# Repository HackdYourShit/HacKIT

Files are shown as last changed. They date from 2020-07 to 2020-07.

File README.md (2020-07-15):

# HacKIT
a low to high tech civic privacy hard(wear) kit for the reclaiming, redesigning, and hacking of the Amazon Echo, Google Home, Apple Siri.

Go [here](https://www.instructables.com/id/HacKIT-a-Civic-Privacy-Hardwear-Kit-for-Hacking-Al/) for a step-by-step build guide for HacKIT.

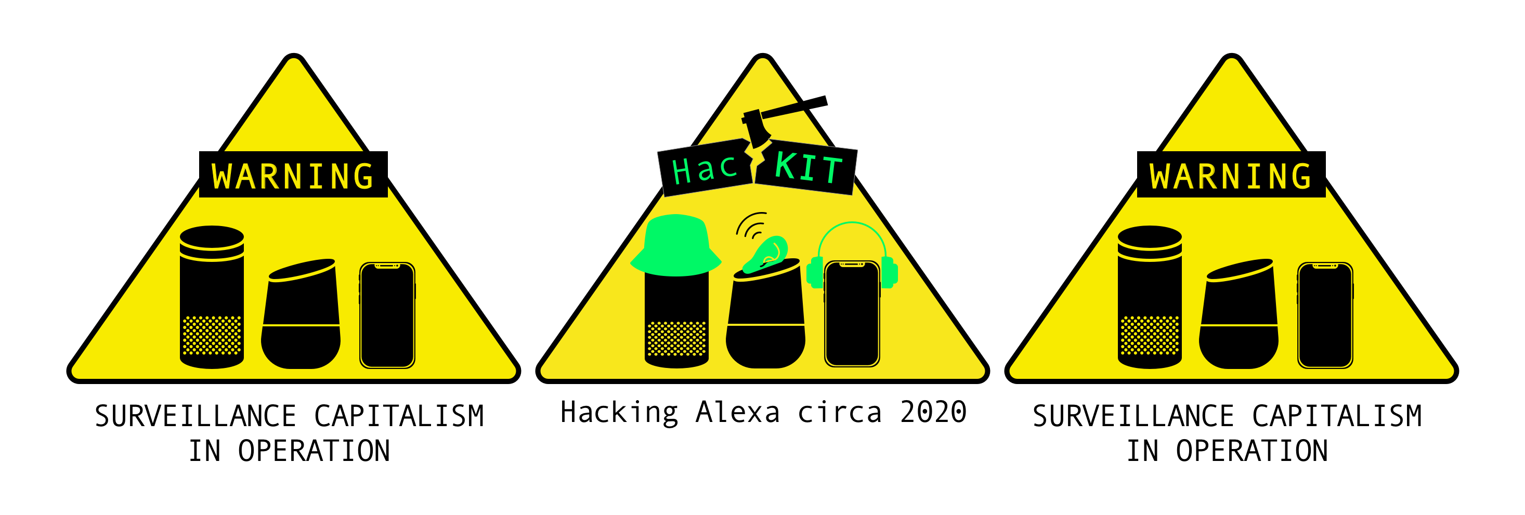
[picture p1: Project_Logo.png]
GitHub Logo


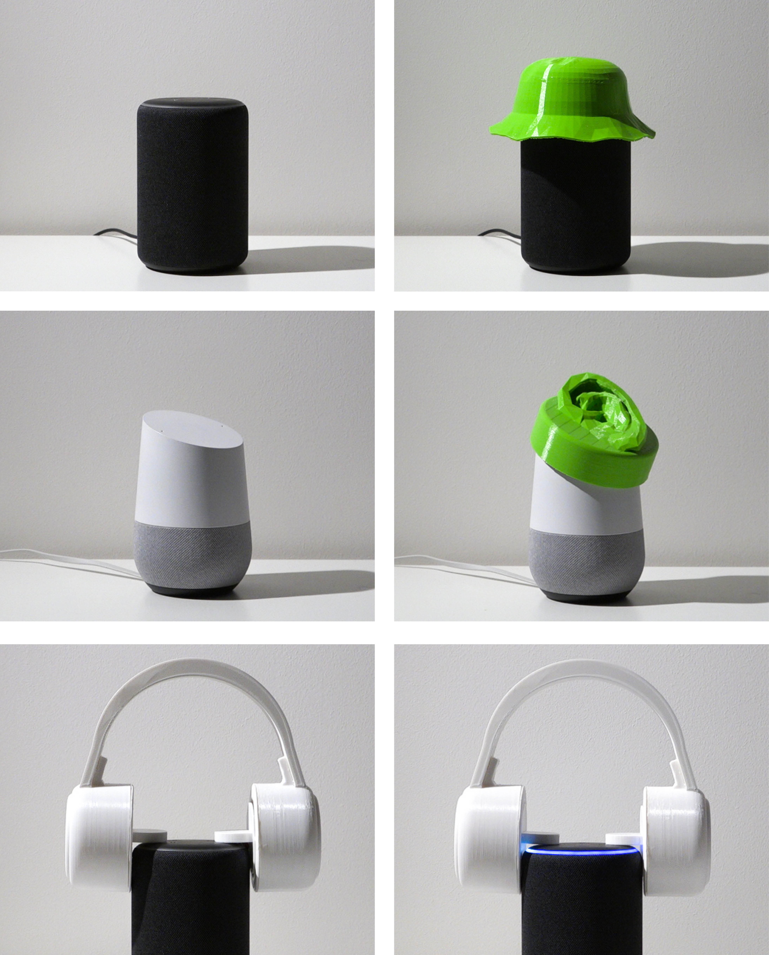
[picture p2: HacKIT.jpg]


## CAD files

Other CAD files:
Rhino_CAD_files/Bucket Hat model_Echo Gen3.3dm
Rhino_CAD_files/Ear model_Google Home.3dm
Rhino_CAD_files/Headphones model_Echo Gen3.3dm

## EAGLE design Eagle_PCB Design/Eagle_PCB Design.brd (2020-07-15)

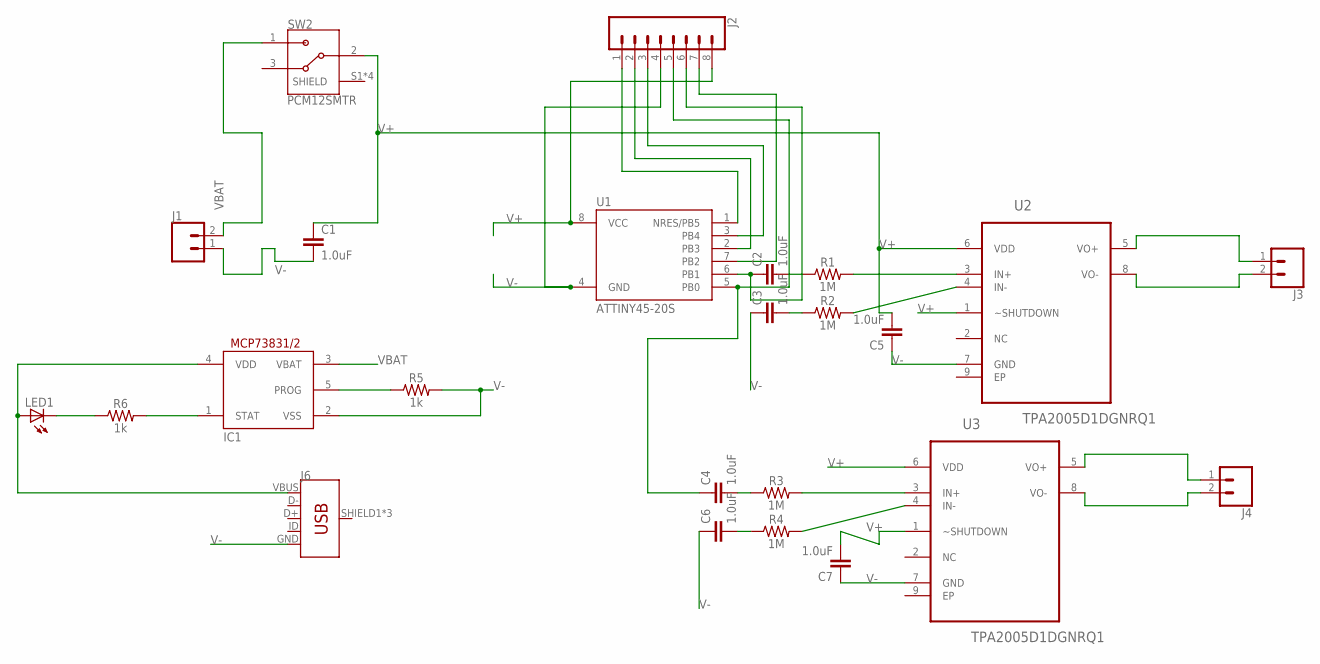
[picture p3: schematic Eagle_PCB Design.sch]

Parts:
C1, C2, C3, C4, C5, C6, C7: 1.0uF; 0603
IC1: MCP73831/OT; SOT23-5L
J1, J3, J4: CONN_02PTH3; 1X02_LONGPADS
J2: CONN_08NO_SILK_FEMALE_PTH; 1X08_NO_SILK
J6: USB_MICRO-B_FEMALE-SMT; USB-B-MICRO-SMD
LED1: LEDCHIPLED_0603; CHIPLED_0603
R1, R2, R3, R4: 1M; 0603
R5, R6: 1k; 0603
SW2: PCM12SMTR; SW_PCM12SMTR
U1: ATTINY45-20S; SOIC8_EIAJ_208MIL
U2, U3: TPA2005D1DGNRQ1; SOP65P490X110-9N

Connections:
unnamed: C2.2, R1.1
unnamed: R1.2, U2.3 (IN+)
unnamed: J3.1, U2.5 (VO+)
unnamed: J3.2, U2.8 (VO-)
unnamed: C2.1, J2.6, U1.6 (PB1)
unnamed: R2.2, U2.4 (IN-)
unnamed: C3.2, R2.1
unnamed: C6.2, R4.1
unnamed: J2.1, U1.1 (NRES/PB5)
unnamed: J2.2, U1.2 (PB3)
unnamed: J2.3, U1.3 (PB4)
unnamed: IC1.4 (VDD), J6.VBUS, LED1.A
unnamed: J4.1, U3.5 (VO+)
unnamed: J2.7, U1.7 (PB2)
unnamed: J4.2, U3.8 (VO-)
unnamed: R3.2, U3.3 (IN+)
unnamed: R4.2, U3.4 (IN-)
unnamed: C4.2, R3.1
unnamed: C4.1, J2.5, U1.5 (PB0)
unnamed: IC1.5 (PROG), R5.1
unnamed: LED1.C, R6.1
unnamed: IC1.1 (STAT), R6.2
V+: C1.1, C5.2, C7.2, J2.8, SW2.2, U1.8 (VCC), U2.1 (~SHUTDOWN), U2.6 (VDD), U3.1 (~SHUTDOWN), U3.6 (VDD)
V-: C1.2, C3.1, C5.1, C6.1, C7.1, IC1.2 (VSS), J1.1, J2.4, J6.GND, R5.2, U1.4 (GND), U2.7 (GND), U3.7 (GND)
VBAT: IC1.3 (VBAT), J1.2, SW2.1

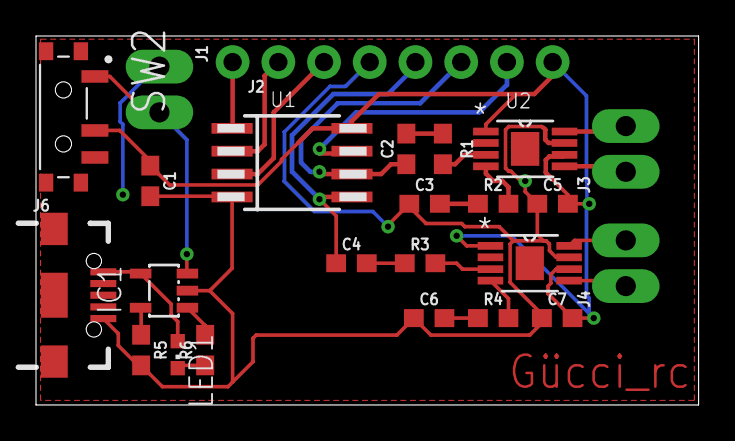
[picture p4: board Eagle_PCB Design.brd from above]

Board: 2 copper layers, 36.8 x 20.5 mm, 24 parts (0 on the bottom side), 25 nets.

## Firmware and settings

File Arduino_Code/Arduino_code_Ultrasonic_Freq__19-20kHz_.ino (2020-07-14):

/*
HacKIT
Programming ATtiny45 - Ultrasonic frequency plays in the 19-20kHz range
*/

void setup() {
  DDRB = 0b00000011;
  PORTB = 0b00000001;
  TCCR0A = 0b00010010; // timer 0
  TCCR0B = 0b00000001; // timer 0
  OCR0A = 200;
  OCR0B = 200;
}

int timer = 0;

void loop() {
 
 byte offset_1 = random(15); // timer 0
 OCR0A = 190 + offset_1;
 OCR0B = 190 + offset_1;
 delayMicroseconds(5);


}

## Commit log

2020-07-14 Create Audio Samples
2020-07-15 created folders
    [Bucket Hat model_Echo Gen3.3dm, Ear model_Google Home.3dm, Headphones model_Echo Gen3.3dm]
2020-07-15 Edited folder names
    [Bucket Hat model_Echo Gen3.3dm, Ear model_Google Home.3dm, Headphones model_Echo Gen3.3dm]
2020-07-15 Eagle PCB Design
    [Eagle_PCB Design.brd, Eagle_PCB Design.sch]
2020-07-15 Audio Samples

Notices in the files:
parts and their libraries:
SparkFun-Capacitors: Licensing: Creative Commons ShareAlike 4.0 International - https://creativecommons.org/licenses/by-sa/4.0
